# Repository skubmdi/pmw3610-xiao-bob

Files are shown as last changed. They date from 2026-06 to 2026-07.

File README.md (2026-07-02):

# PMW3610-SUDU XIAO Breakoutboard
This product is a breakout board for the PMW3610-SUDU.
<br>It features a compact design that shares the same form factor as the Seeed Studio XIAO series.
<br>It operates exclusively at 3.3V and is designed to be used in conjunction with a XIAO module.

# Dimensional Drawing
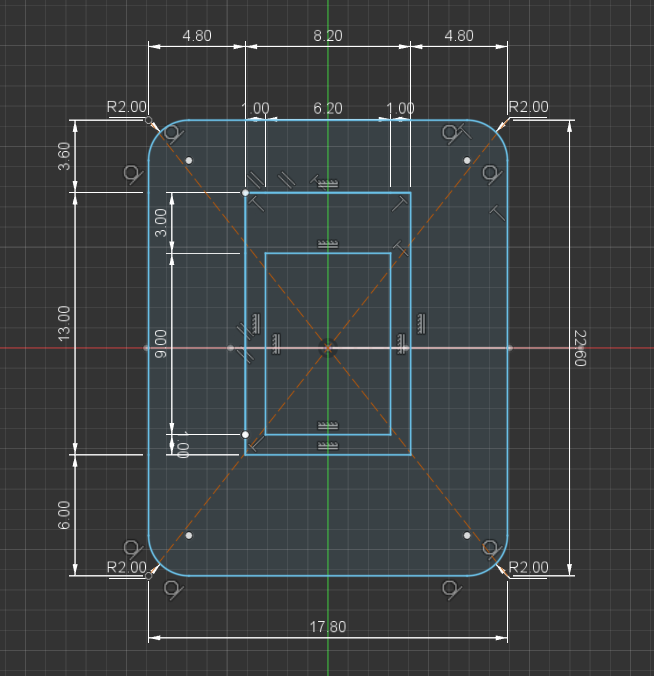
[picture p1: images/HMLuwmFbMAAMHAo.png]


- SMD components protrude 2 mm.<br>
- The lens protrudes 3 mm from the circuit board.<br>

# Pin Assign
## 2.54mm Pitch Pin Header

SDIO / SCLK / NCS / MOTION / 3V3 / GND



## 0.50mm Pitch FPC Connector

3V3 / MOTION / NCS / SCLK / SDIO / GND

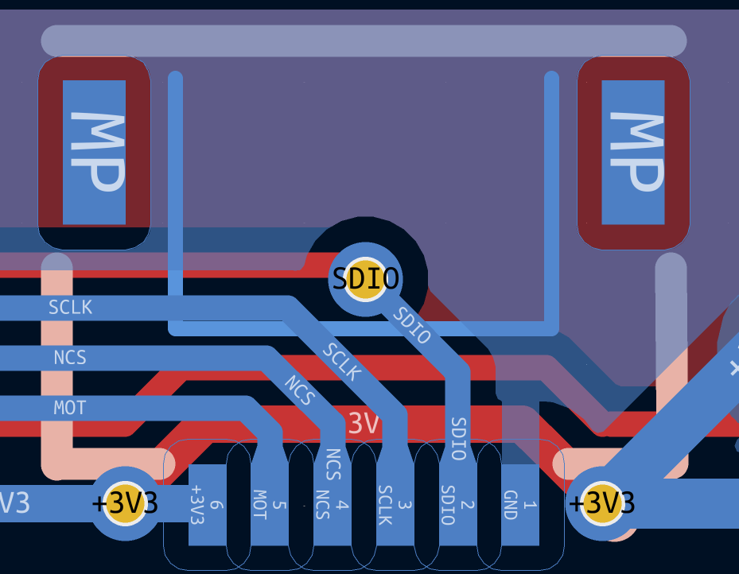
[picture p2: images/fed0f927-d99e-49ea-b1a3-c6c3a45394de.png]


# Kicad PCB Preview
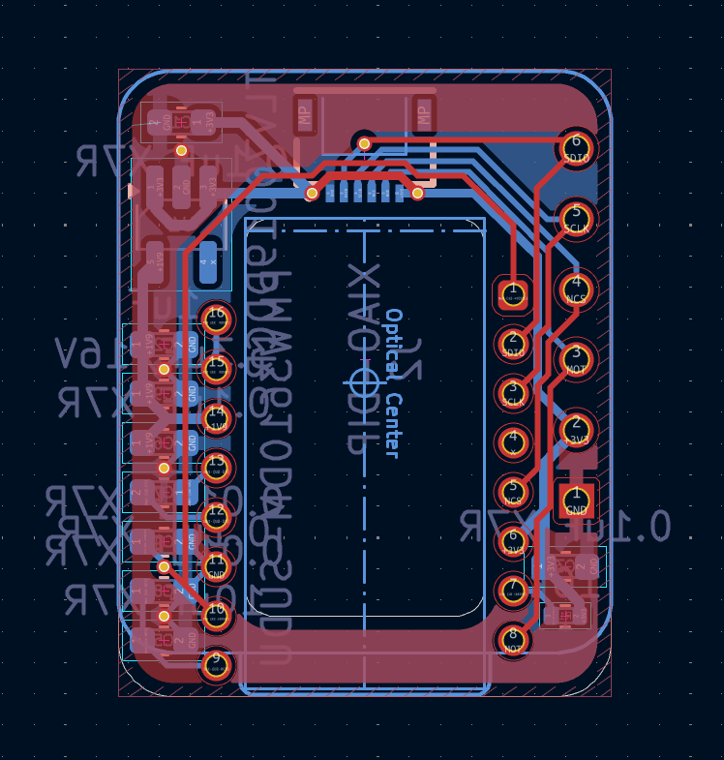
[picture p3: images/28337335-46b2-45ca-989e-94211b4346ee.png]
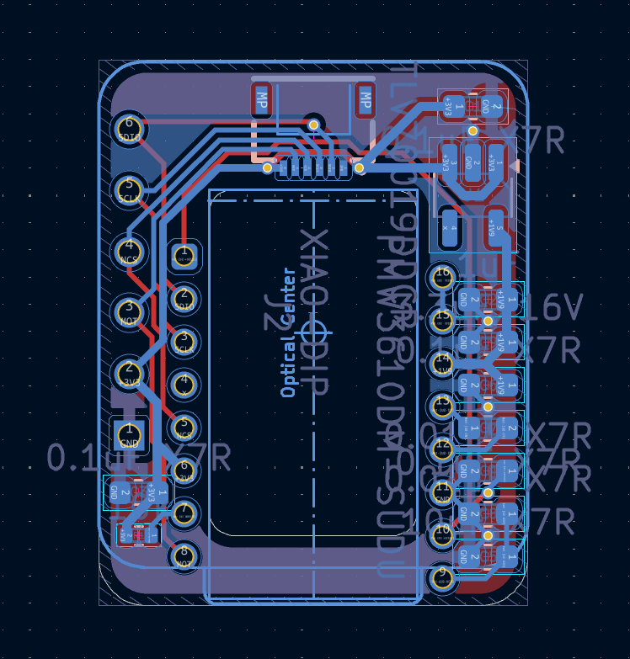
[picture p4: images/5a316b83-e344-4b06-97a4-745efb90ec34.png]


# Mounted the SMD components and sensors
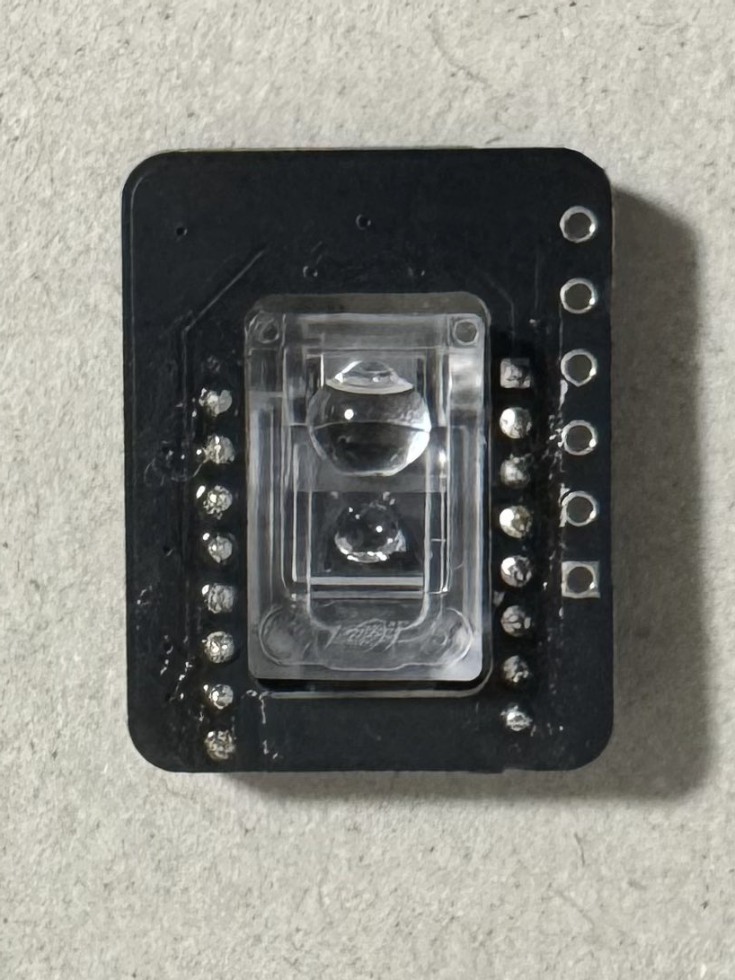
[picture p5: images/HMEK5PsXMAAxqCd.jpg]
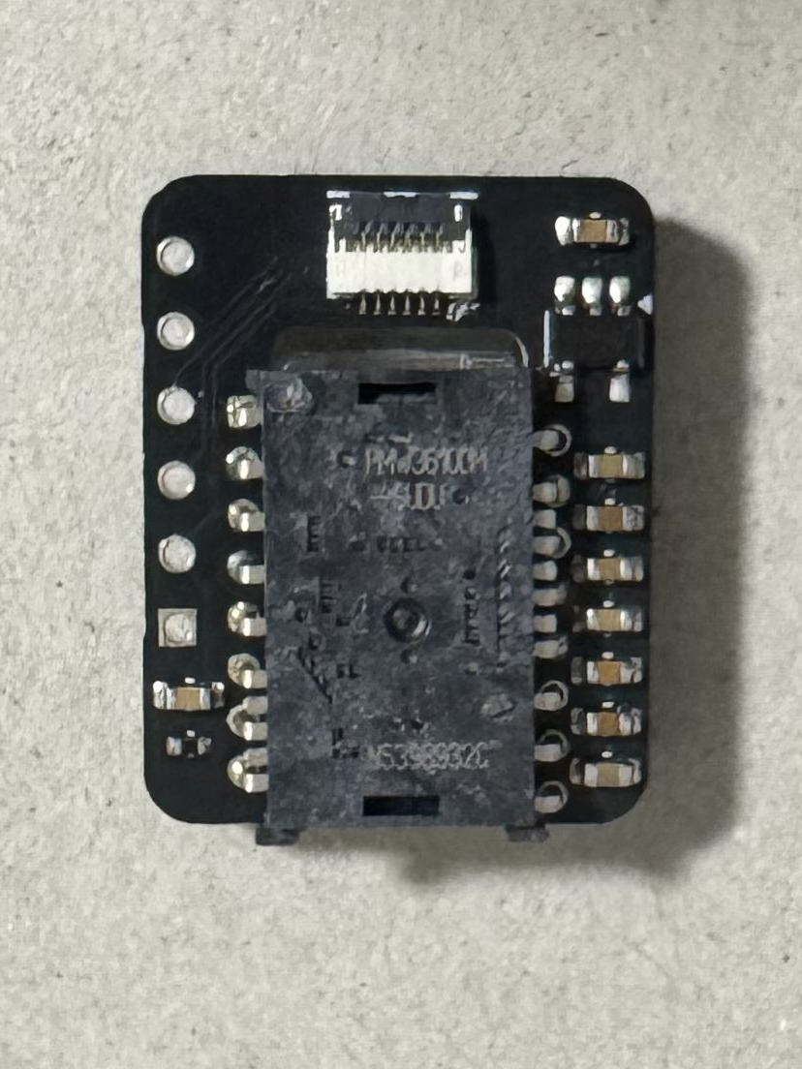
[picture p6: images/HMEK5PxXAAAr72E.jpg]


# With SeeedStudio XIAO (nRF52840-Plus)
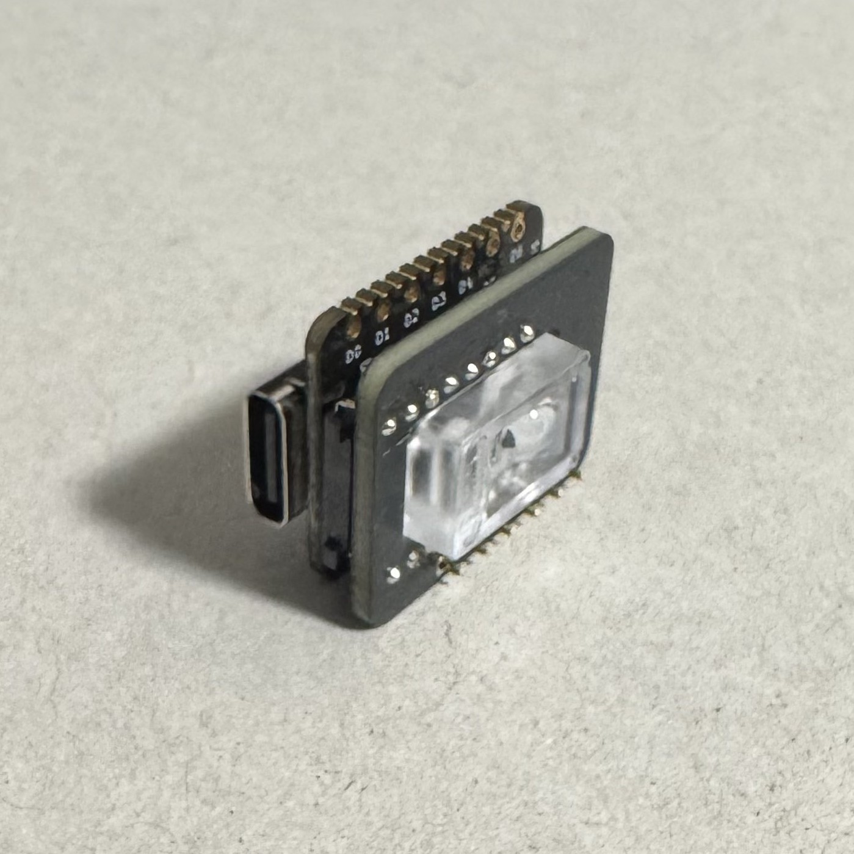
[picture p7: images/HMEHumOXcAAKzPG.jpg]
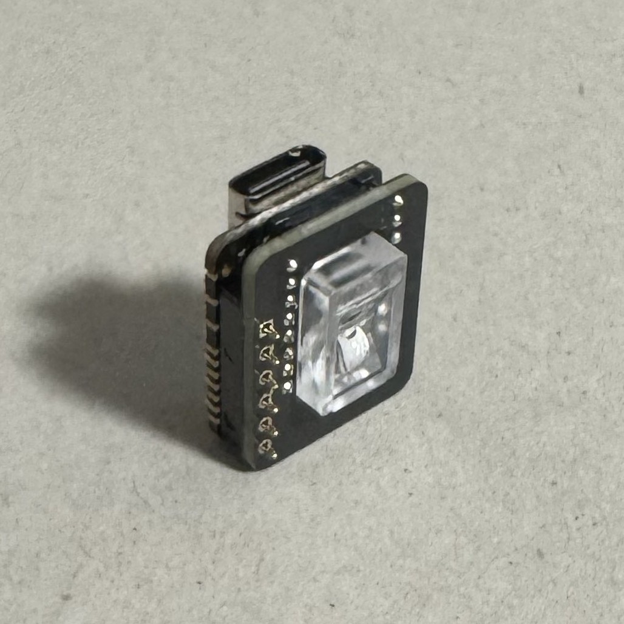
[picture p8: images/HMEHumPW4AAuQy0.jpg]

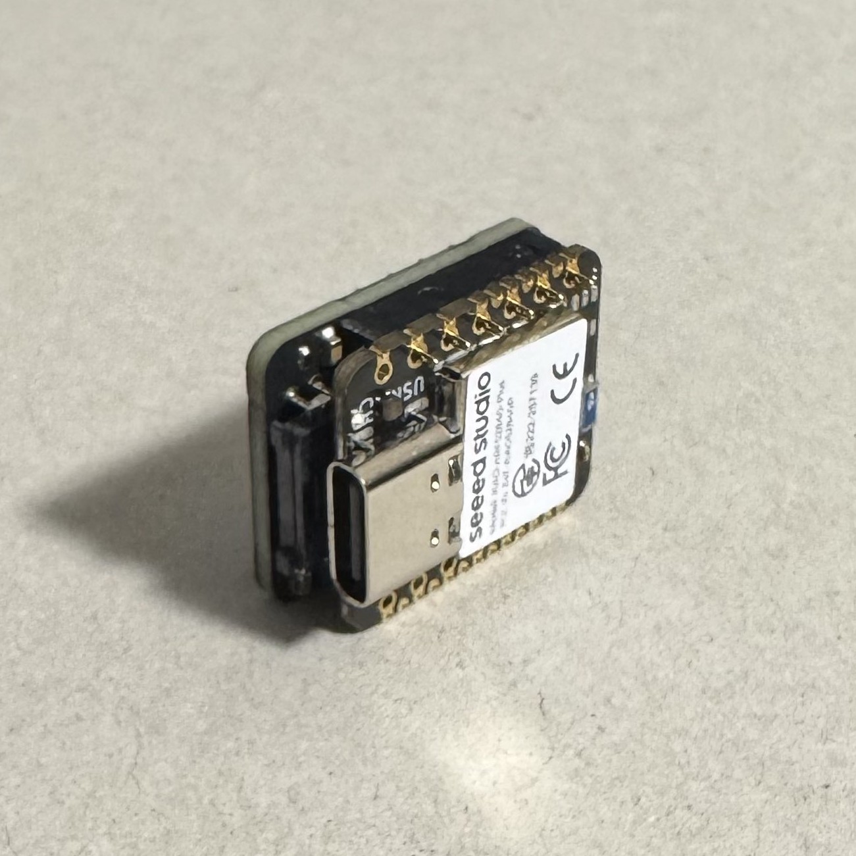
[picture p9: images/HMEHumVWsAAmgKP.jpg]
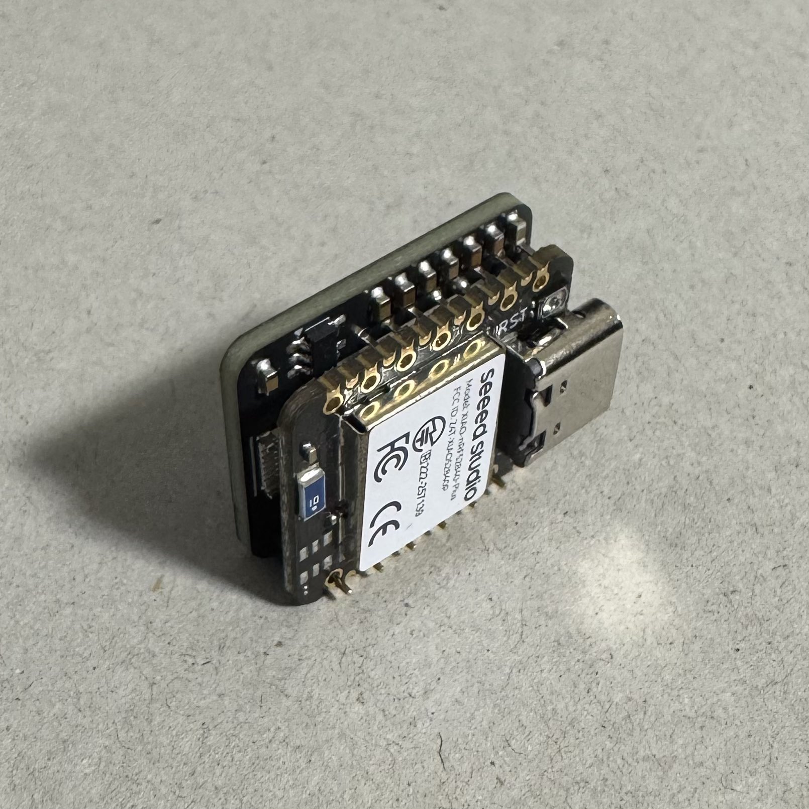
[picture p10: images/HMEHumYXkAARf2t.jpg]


# STL Sample
<i>under preparation</i>

# ZMK Sample
https://github.com/skubmdi/zmk-config-pmw3610-xiao

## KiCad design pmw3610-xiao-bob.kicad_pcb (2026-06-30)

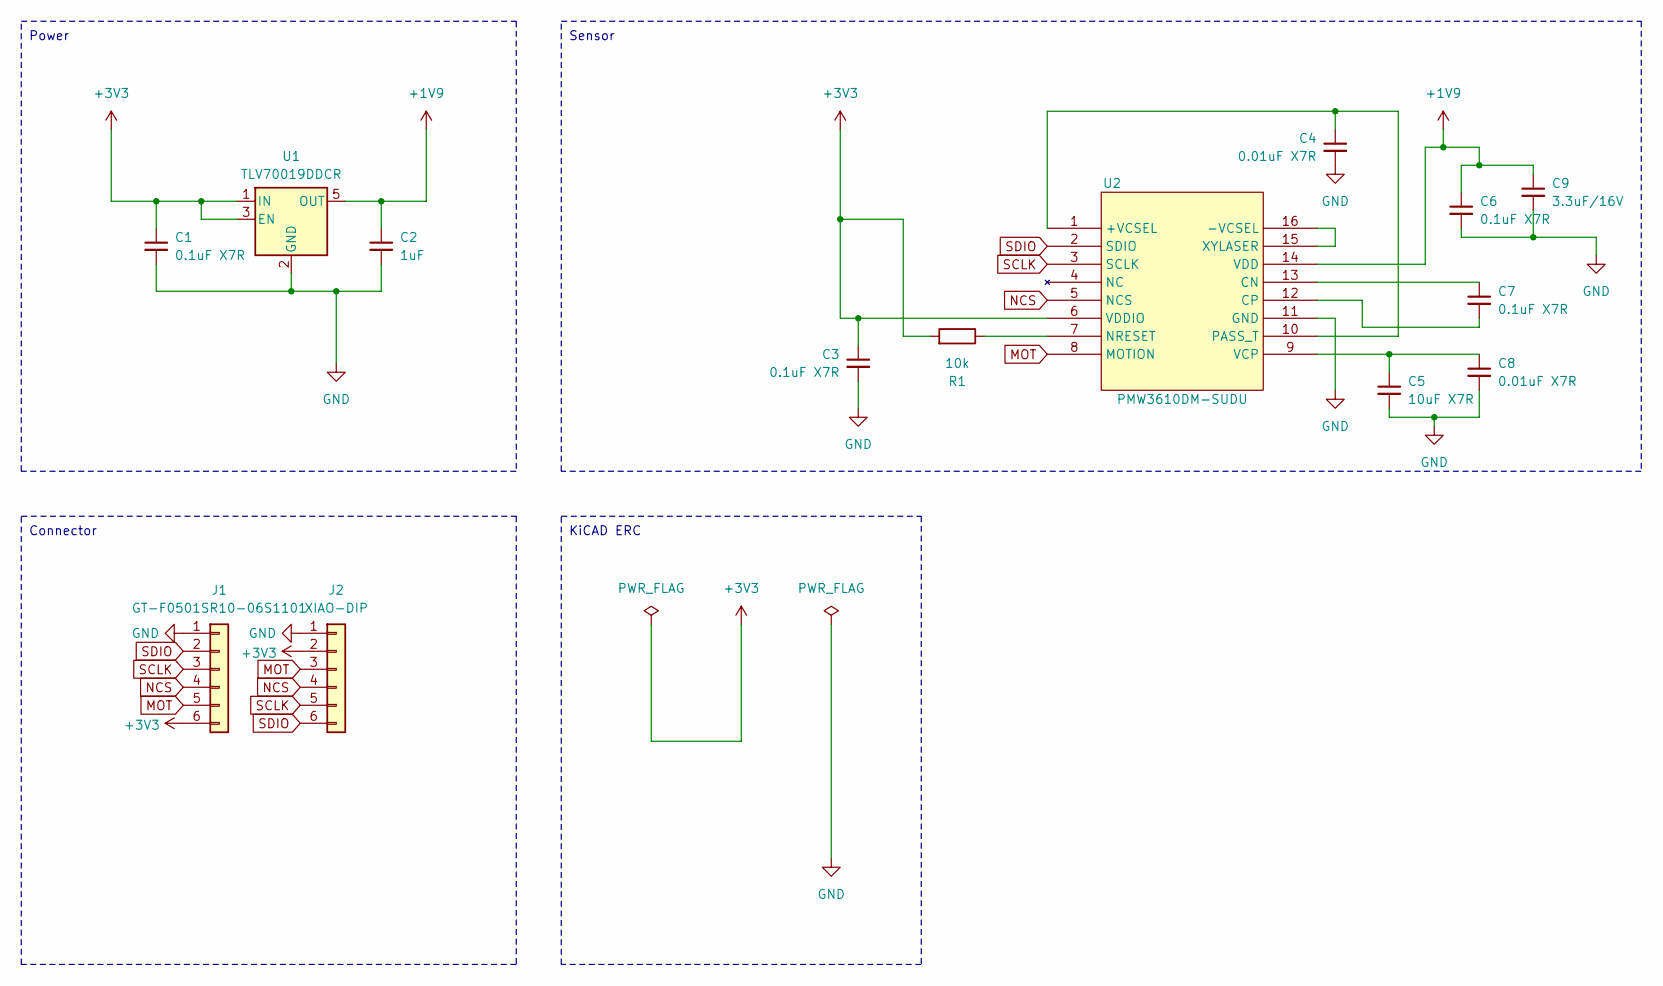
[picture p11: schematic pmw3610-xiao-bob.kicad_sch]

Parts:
C1, C3, C6, C7: 0.1uF X7R; C_0603_1608Metric
C2: 1uF; C_0603_1608Metric
C4, C8: 0.01uF X7R; C_0603_1608Metric
C5: 10uF X7R; C_0603_1608Metric
C9: 3.3uF/16V; C_0603_1608Metric
J1: GT-F0501SR10-06S1101
J2: XIAO-DIP
R1: 10k; R_0402_1005Metric
U1: TLV70019DDCR; SOT-23-5_HandSoldering
U2: PMW3610DM-SUDU

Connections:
+1V9: C2.1, C6.1, C9.1, U1.5 (OUT), U2.14 (VDD)
+3V3: C1.1, C3.1, J1.6, J2.2, R1.2, U1.1 (IN), U1.3 (EN), U2.6 (VDDIO)
GND: C1.2, C2.2, C3.2, C4.2, C5.2, C6.2, C8.2, C9.2, J1.1, J2.1, U1.2 (GND), U2.11 (GND)
MOT: J1.5, J2.3, U2.8 (MOTION)
NCS: J1.4, J2.4, U2.5 (NCS)
unnamed: C4.1, U2.1 (+VCSEL), U2.10 (PASS_T)
unnamed: U2.15 (XYLASER), U2.16 (-VCSEL)
unnamed: C7.1, U2.13 (CN)
unnamed: C7.2, U2.12 (CP)
unnamed: R1.1, U2.7 (NRESET)
unnamed: C5.1, C8.1, U2.9 (VCP)
SCLK: J1.3, J2.5, U2.3 (SCLK)
SDIO: J1.2, J2.6, U2.2 (SDIO)

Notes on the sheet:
Power
Sensor
Connector
KiCAD ERC

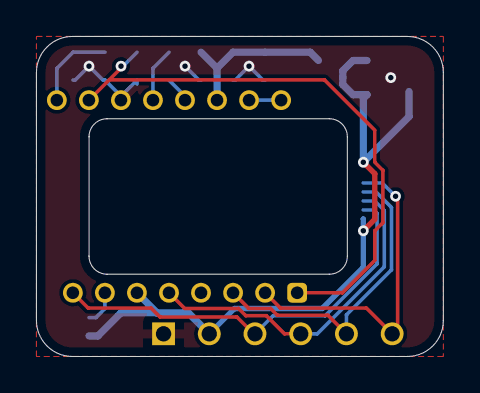
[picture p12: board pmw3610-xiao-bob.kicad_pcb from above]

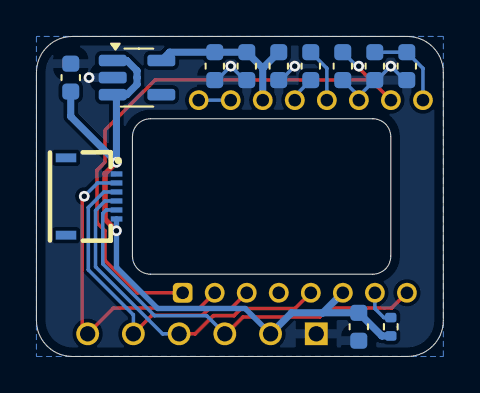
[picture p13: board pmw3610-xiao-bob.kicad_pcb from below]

Board: 2 copper layers, 22.6 x 17.8 mm, 14 parts (14 on the bottom side), 13 nets.
